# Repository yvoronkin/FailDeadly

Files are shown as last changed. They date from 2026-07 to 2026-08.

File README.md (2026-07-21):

# FailDeadly
### Fail Secure. Fail Deadly

FailDeadly is a USB hardware device designed to ensure the physical security of the server. It uses Hall sensors, along with magnets installed on the server lid, to detect any tampering attempt. To make it work, FailDeadly integrates with infrastructure and becomes the main or one of the sources of trust to pass server remote attestation.

FailDeadly stores secrets such as the sign key in SRAM as long as the MCU has power. In case of a tampering attempt when the server lid is moved, device power management detects a change in the magnetic field and cuts off the MCU power supply. FailDeadly destroy in memory secret in one second or less after the tamper event is detected. This time delay allows the MCU to notify the host system about the tamper event through message, SysRq, or hardware reset event.

To be able to keep secrets and reduce the number of maintenance events during power outages, FailDeadly has an Ionister to keep the SRAM powered.

### ** _Warning:_ FailDeadly achives it goals by valuing confidentiality more than availability. Be aware.**

Features:

* Physical tamper detection
* In-memory secret storage
* Power cut off on bare logic - no way to cancel 
* Secret destruction in case of tampering event
* SysRq or Reset pin could be used to reset the host system.
* On-board ionistor connector to keep secrets through power outages
* HashiCorp Vault integration
* On-device encrypt/decrypt, sign/verity operations.
* On-device key generation

Use cases:

* Hardening server physical security
* Remote server attestation
* Burn-out LUKS decryption keys



### TODO:
- [x] Hardware design v1.0 rev 001 
- [ ] Firmware 
- [ ] Software 
- [ ] HashiCorp Vault login plugin

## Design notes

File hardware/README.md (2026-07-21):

# FailDeadly hardware
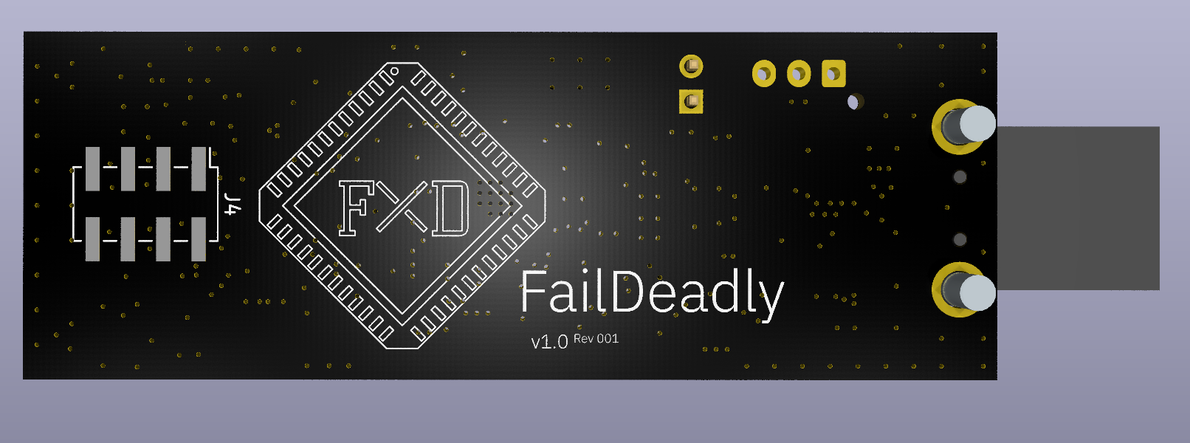
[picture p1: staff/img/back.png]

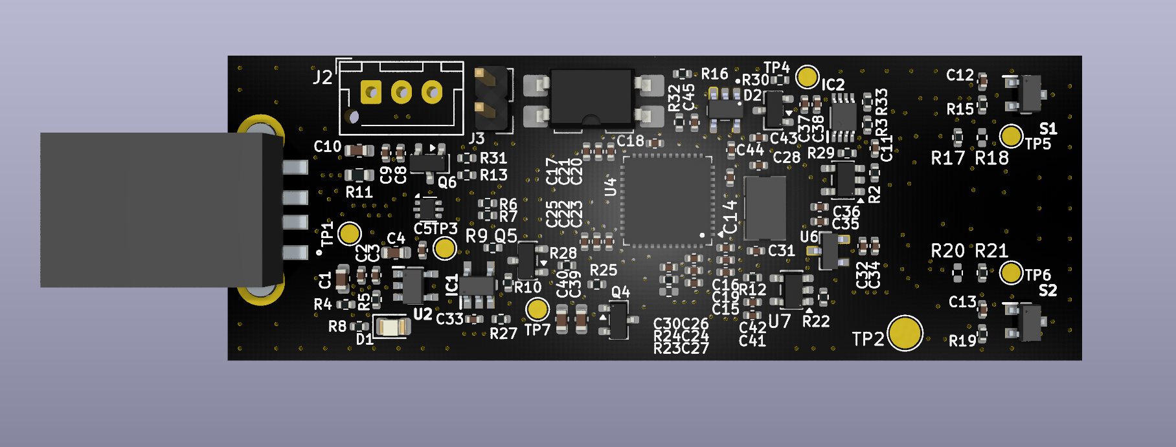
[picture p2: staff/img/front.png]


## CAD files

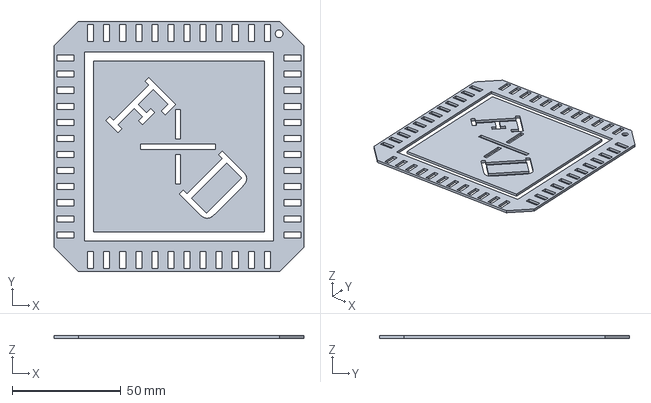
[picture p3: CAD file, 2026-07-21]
staff/logo/logo.FCStd
114.8 x 114.8 x 1.40 mm

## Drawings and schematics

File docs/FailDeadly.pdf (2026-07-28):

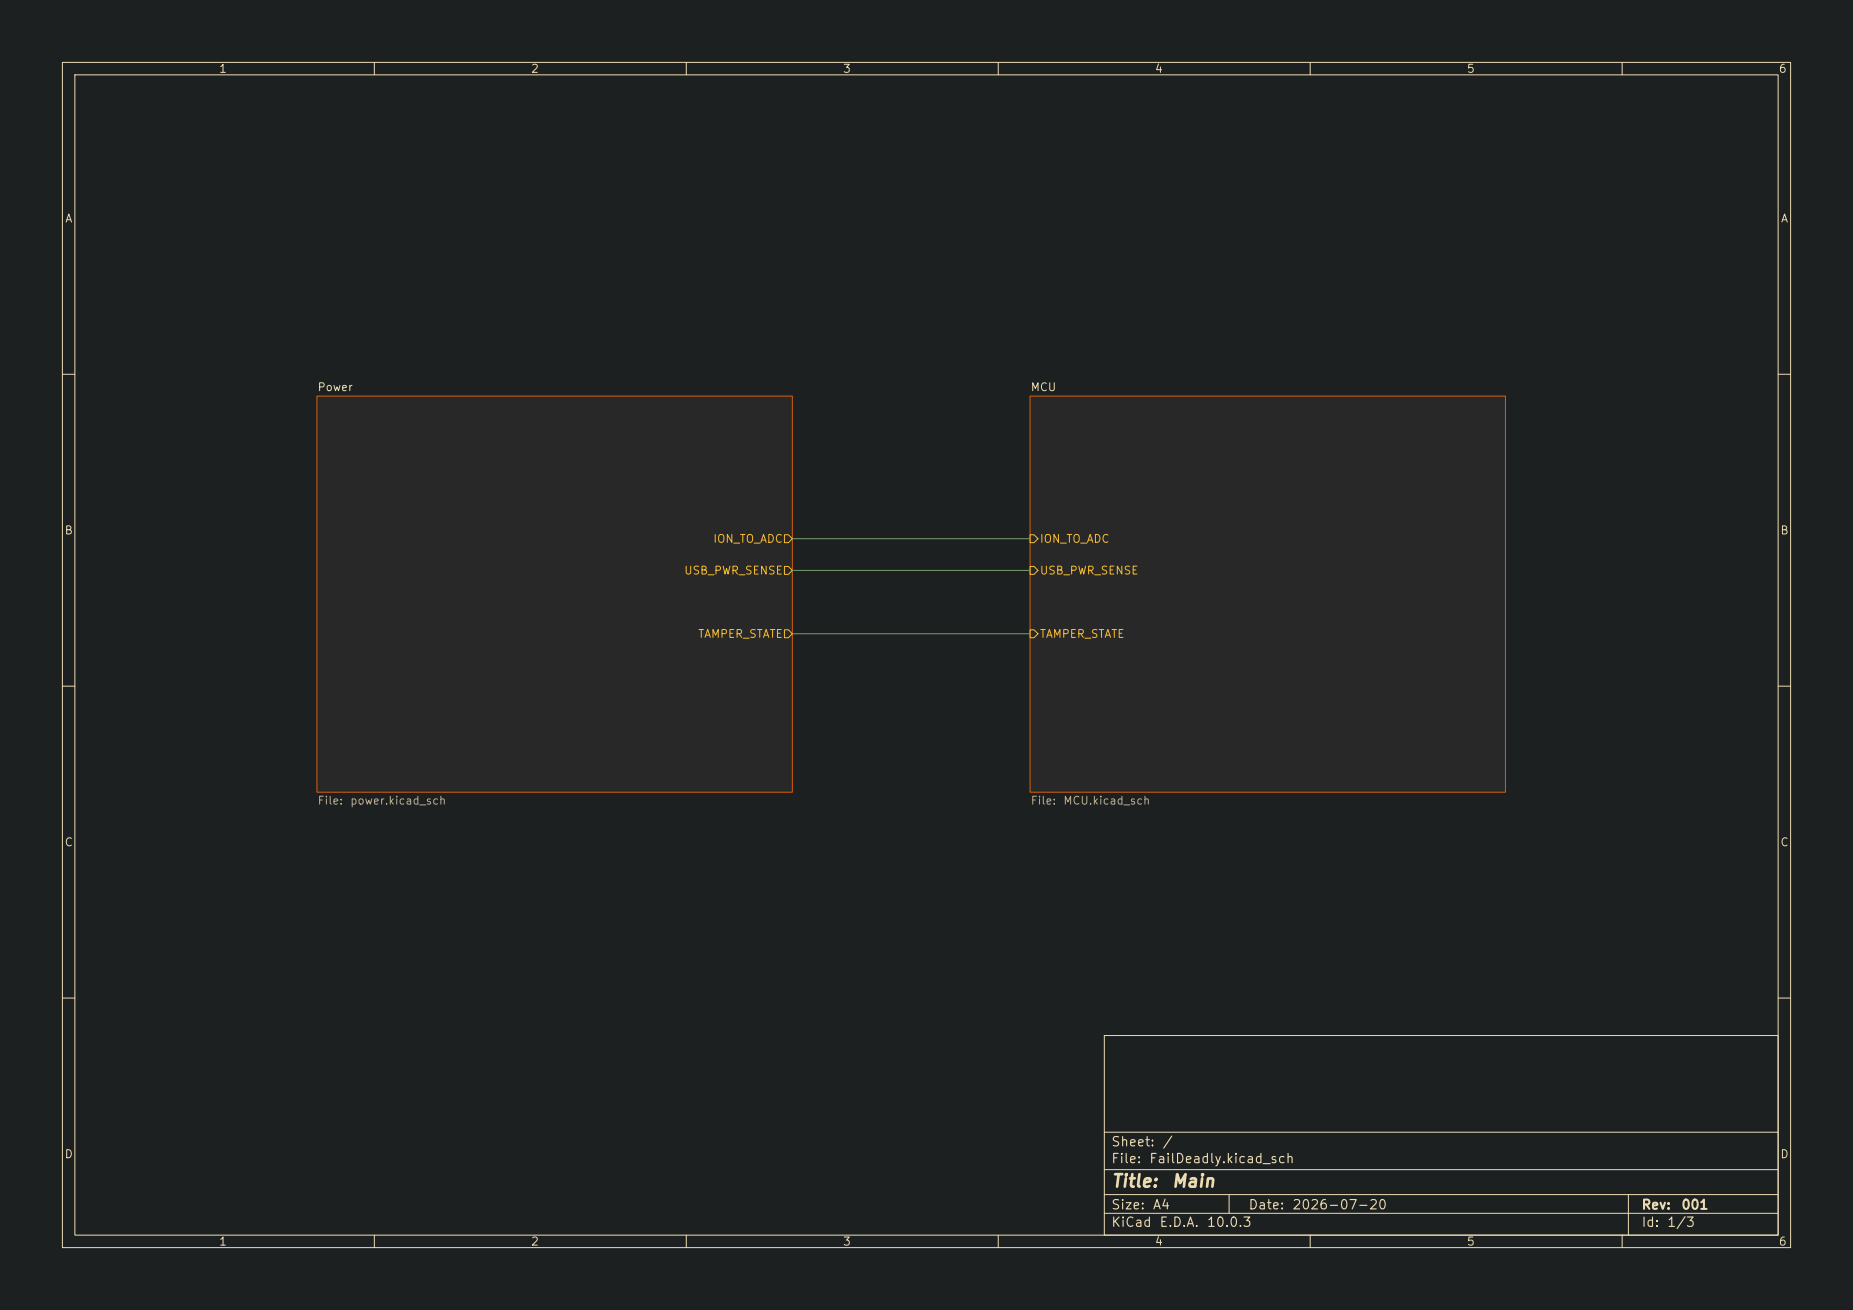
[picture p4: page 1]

Size: A4 | Rev: 001
KiCad E.D.A. 10.0.3 | Id: 1/3

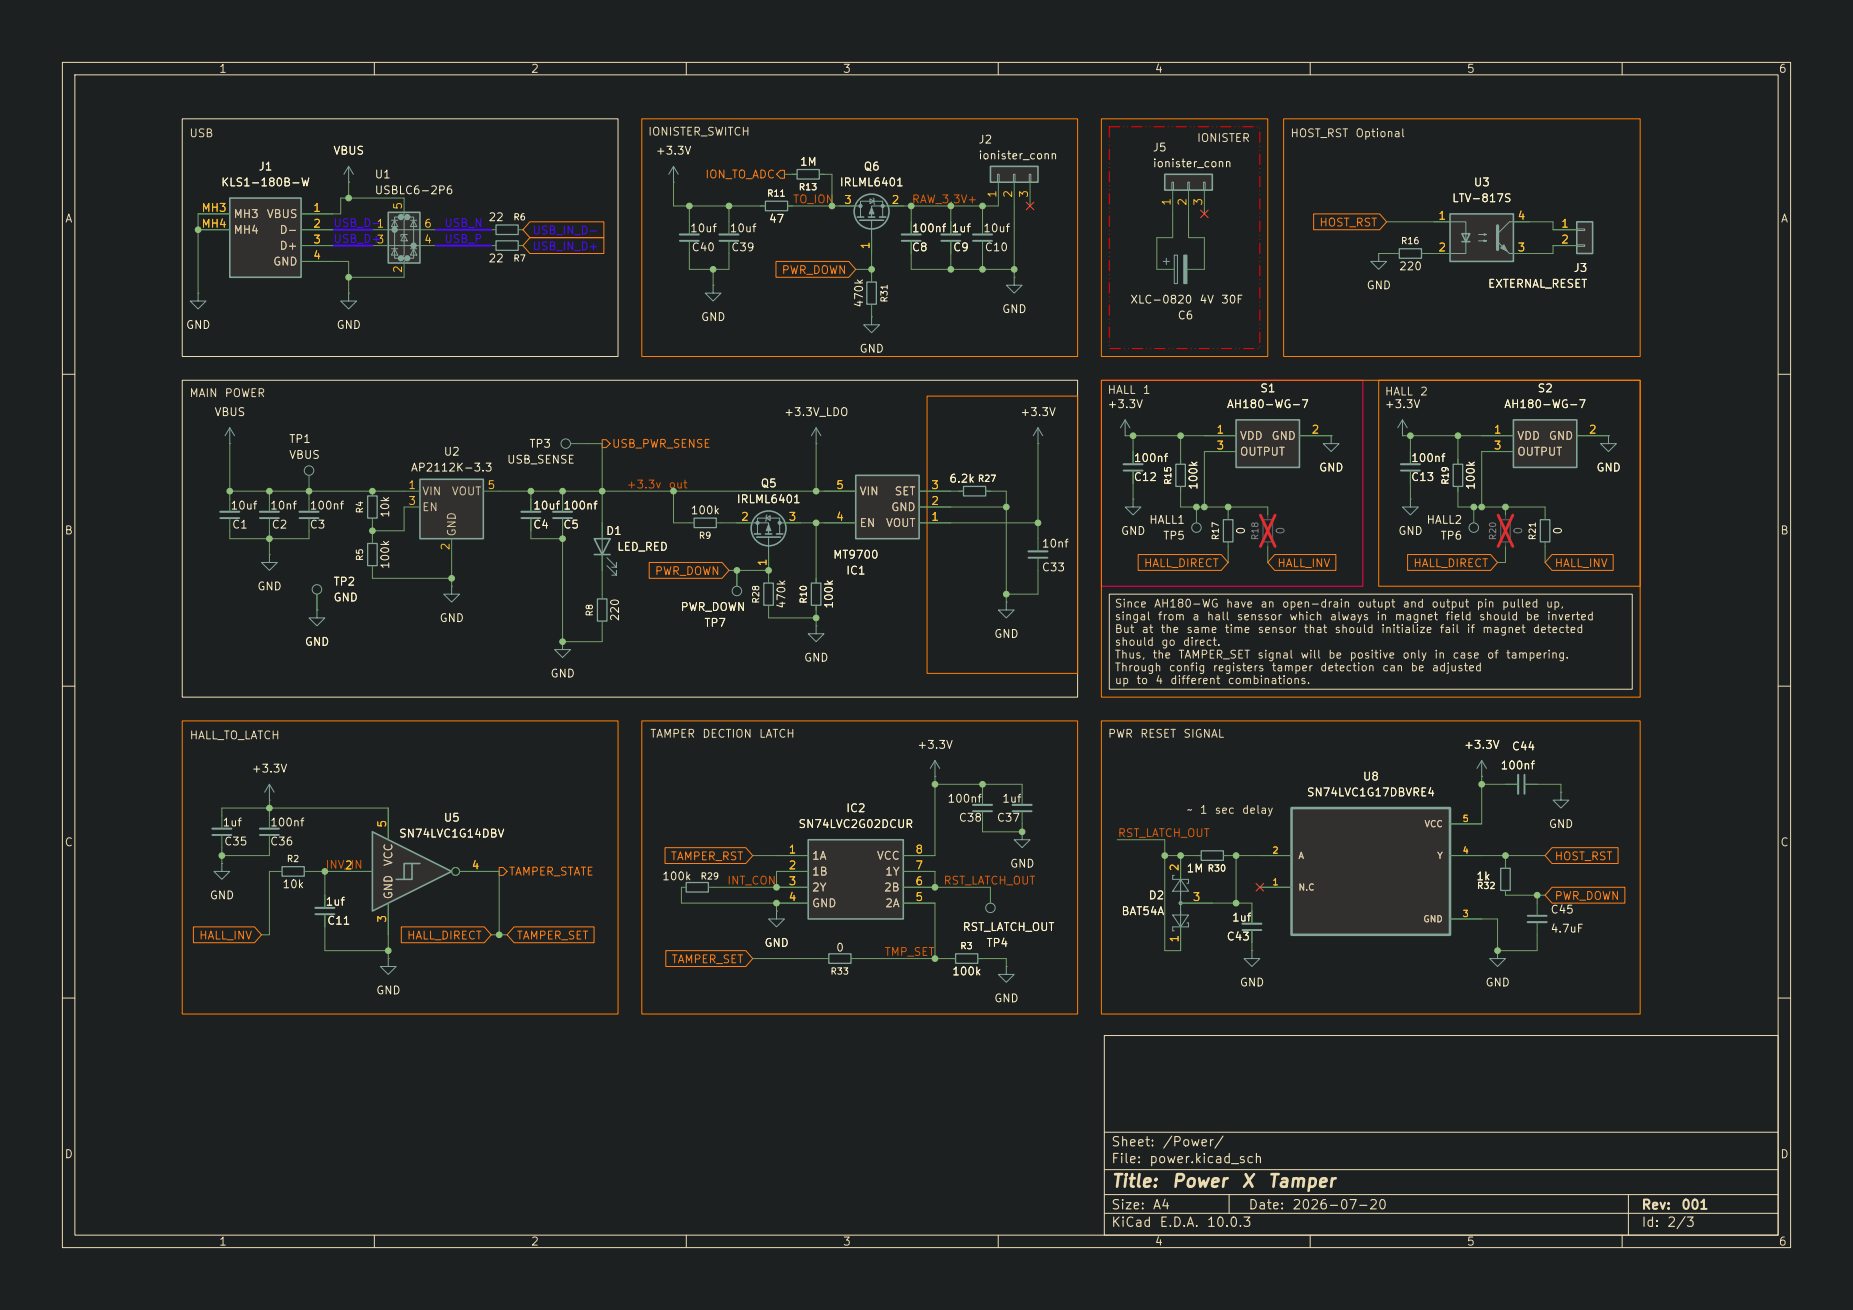
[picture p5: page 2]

Since AH180-WG have an open-drain outupt and output pin pulled up, singal from a hall senssor which always in magnet field should be inverted But at the same time sensor that should initialize fail if magnet detected should go direct. Thus, the TAMPER_SET signal will be positive only in case of tampering.

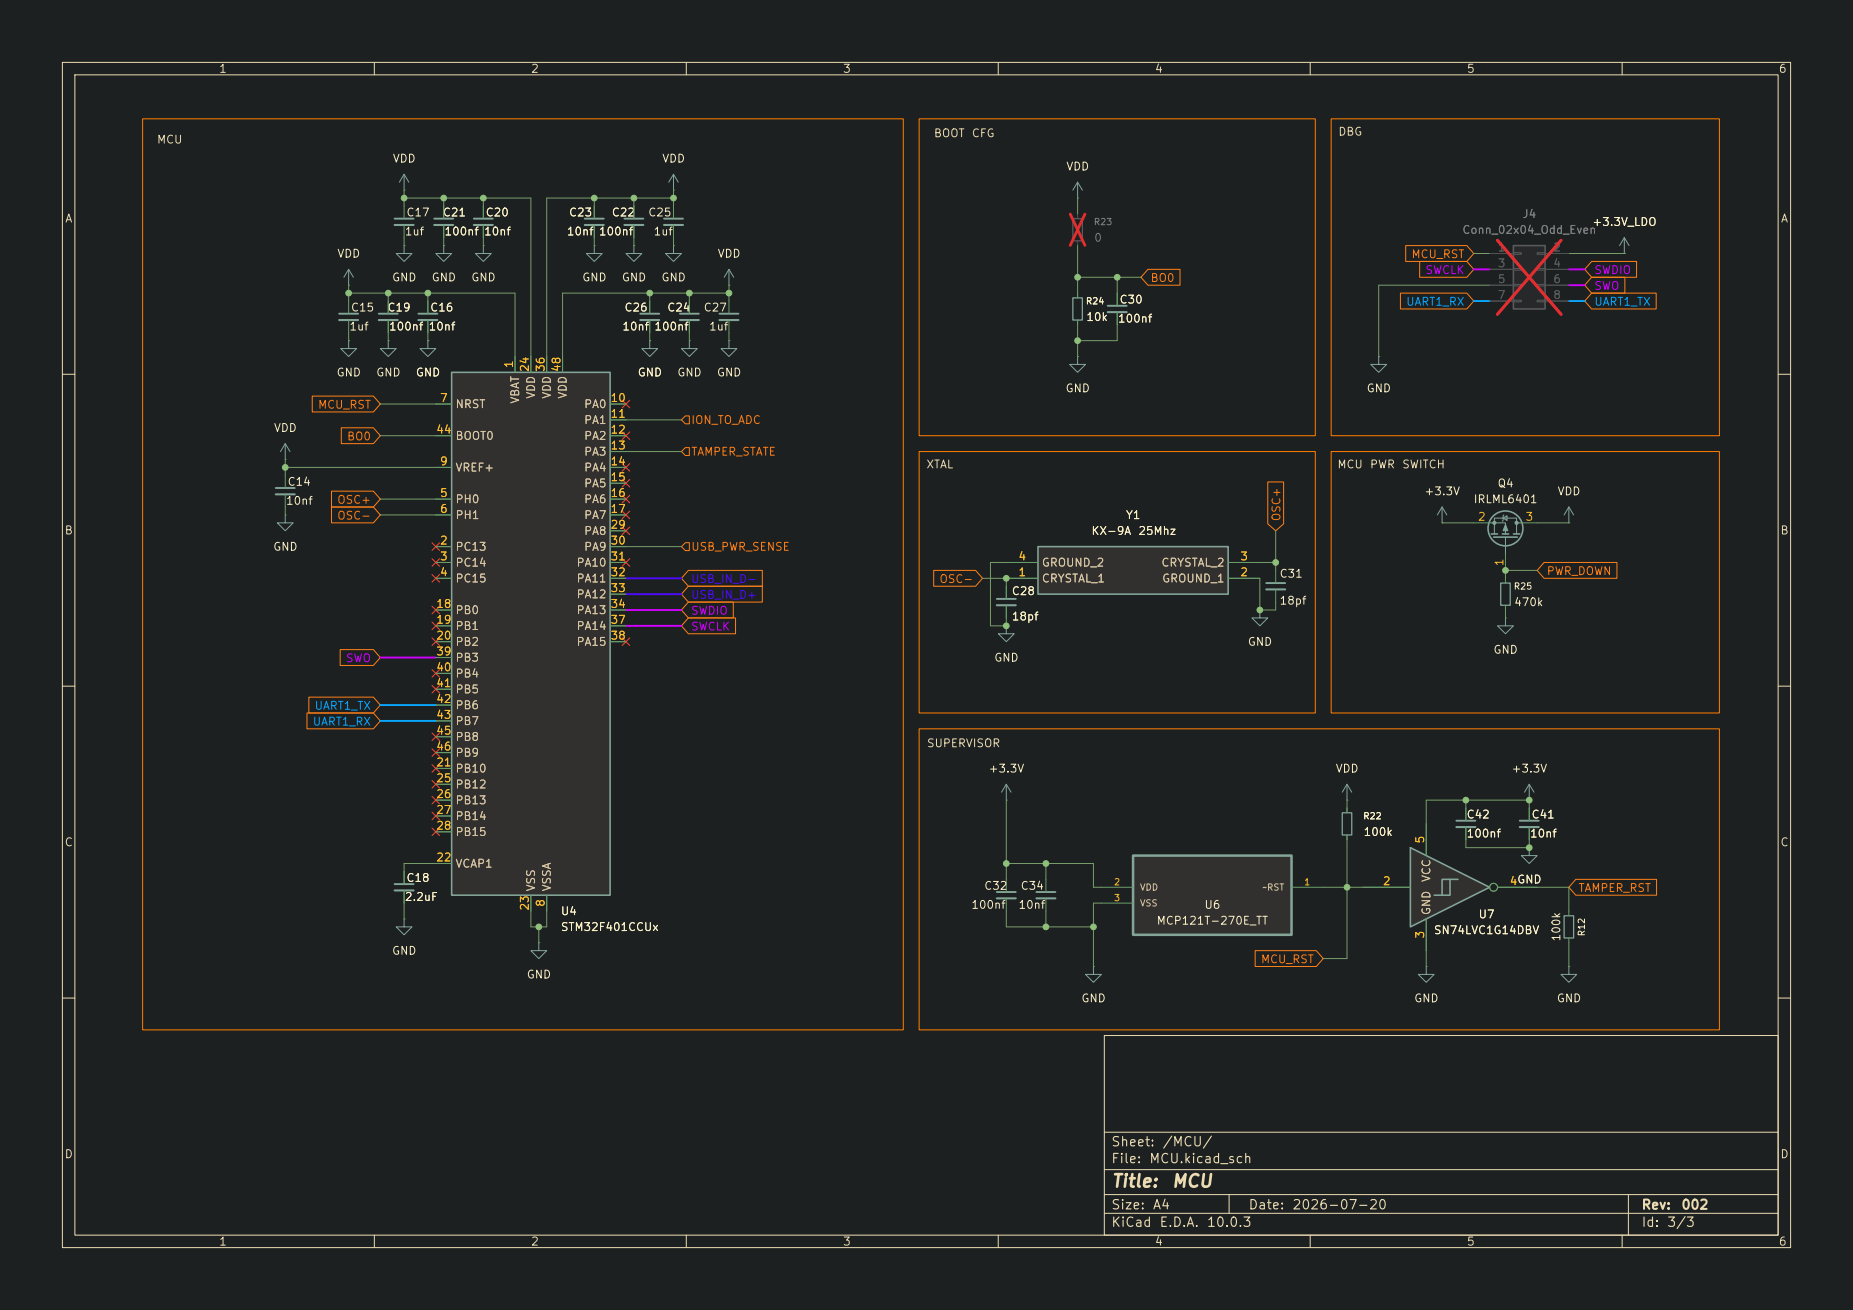
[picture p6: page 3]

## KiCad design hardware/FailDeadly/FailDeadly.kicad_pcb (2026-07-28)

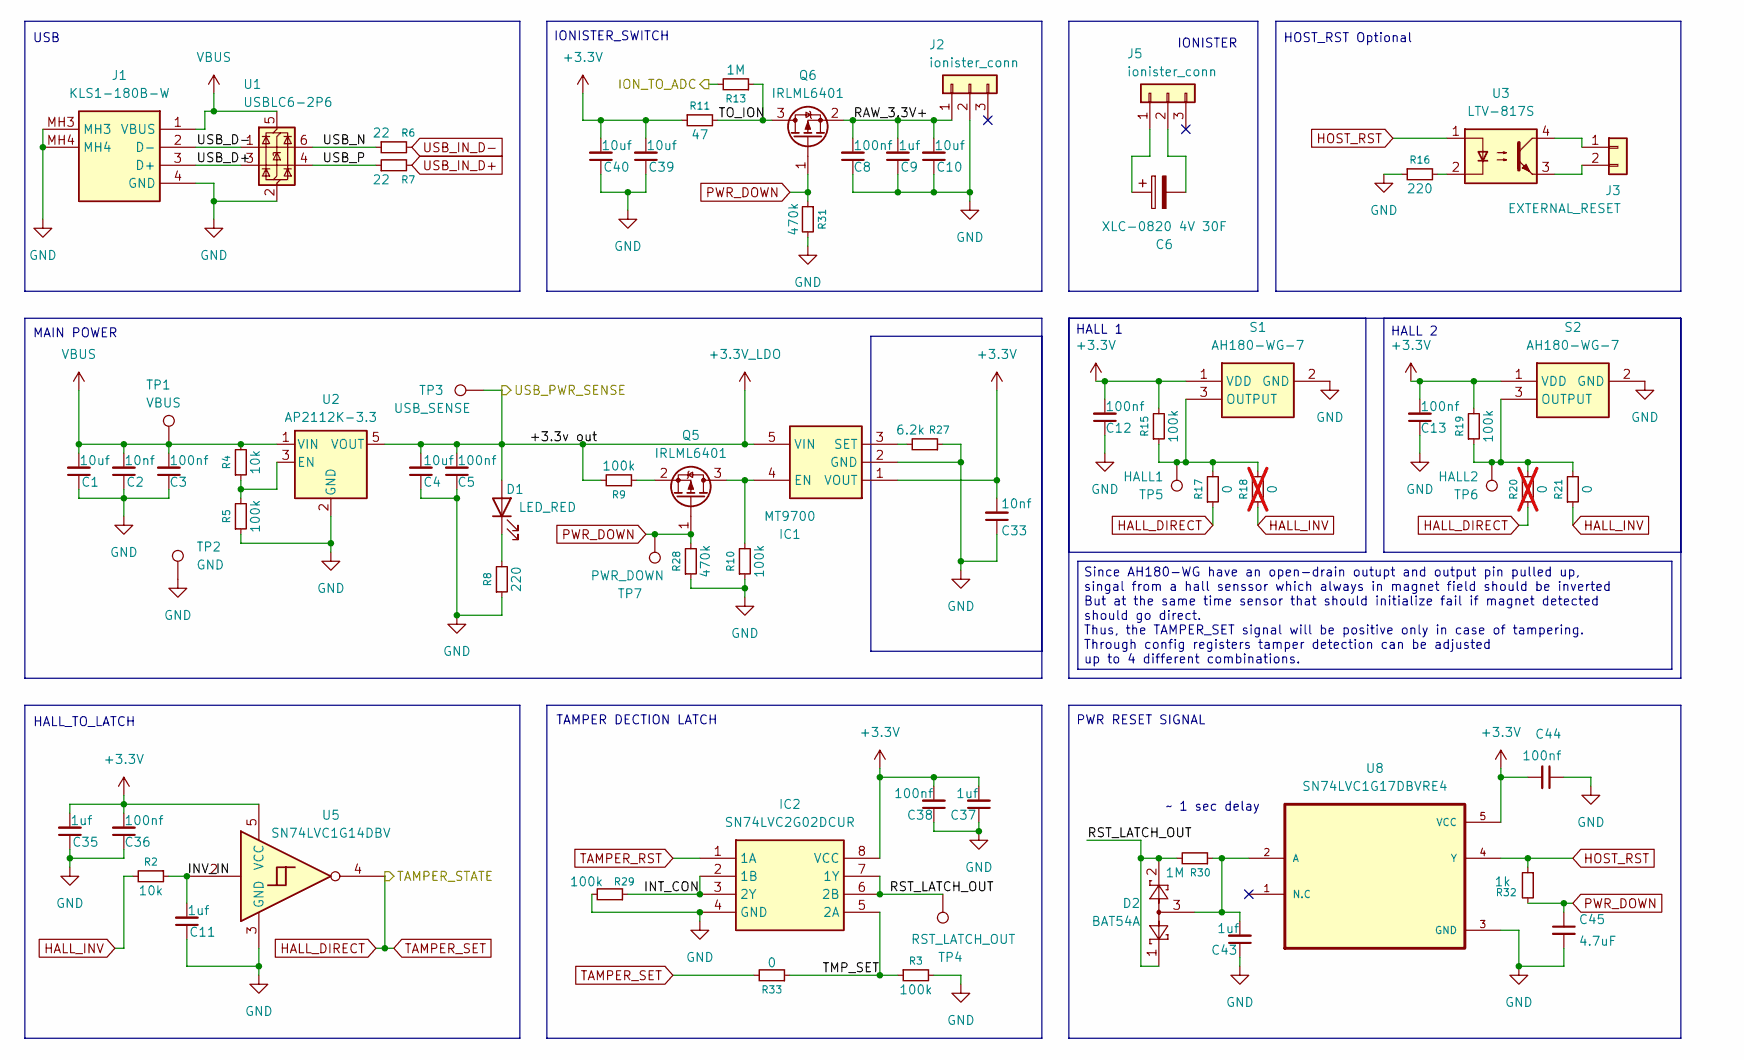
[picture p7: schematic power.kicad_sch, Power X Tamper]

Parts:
C1, C4, C10, C39, C40: 10uf; C_0603_1608Metric
C2, C33: 10nf; C_0402_1005Metric
C3, C5, C8, C12, C13, C36, C38, C44: 100nf; C_0402_1005Metric
C6: XLC-0820 4V 30F
C9, C11, C35, C37, C43: 1uf; C_0402_1005Metric
C45: 4.7uF; C_0603_1608Metric
D1: LED_RED; LED_0805_2012Metric
D2: BAT54A; SOT-23
IC1: MT9700; SOT95P280X135-5N; Manufacturer_Part_Number MT9700
IC2: SN74LVC2G02DCUR; SOP50P310X90-8N; Manufacturer_Part_Number SN74LVC2G02DCUR; Mouser Part Number 595-SN74LVC2G02DCUR
J1: KLS1-180B-W; KLS1180BW; Manufacturer_Part_Number KLS1-180B-W
J2, J5: ionister_conn; JST_XH_B3B-XH-AM_1x03_P2.50mm_Vertical
J3: EXTERNAL_RESET; PinHeader_1x02_P2.54mm_Vertical
Q5, Q6: IRLML6401; SOT-23
R2, R4: 10k; R_0402_1005Metric
R3, R5, R9, R10, R15, R19, R29: 100k; R_0402_1005Metric
R6, R7: 22; R_0402_1005Metric
R8, R16: 220; R_0402_1005Metric
R11: 47; R_0603_1608Metric
R13, R30: 1M; R_0402_1005Metric
R17, R21, R33: 0; R_0402_1005Metric
R18, R20: 0; R_0402_1005Metric; not fitted
R27: 6.2k; R_0402_1005Metric
R28, R31: 470k; R_0402_1005Metric
R32: 1k; R_0402_1005Metric
S1, S2: AH180-WG-7; AH180WG7; Manufacturer_Part_Number AH180-WG-7; Mouser Part Number 621-AH180-WG-7
TP1: VBUS; TestPoint_Pad_D1.5mm
TP2: GND; TestPoint_Pad_D2.5mm
TP3: USB_SENSE; TestPoint_Pad_D1.5mm
TP4: RST_LATCH_OUT; TestPoint_Pad_D1.5mm
TP5: HALL1; TestPoint_Pad_D1.5mm
TP6: HALL2; TestPoint_Pad_D1.5mm
TP7: PWR_DOWN; TestPoint_Pad_D1.5mm
U1: USBLC6-2P6; SOT-666
U2: AP2112K-3.3; SOT-23-5
U3: LTV-817S; SMDIP-4_W9.53mm
U5: SN74LVC1G14DBV; SOT-23-5
U8: SN74LVC1G17DBVRE4; SOT95P280X145-5N

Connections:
+3.3V: C12.2, C13.2, C33.2, C35.2, C36.2, C37.2, C38.2, C39.2, C40.2, C44.2, IC1.1 (VOUT), IC2.8 (VCC), R11.1, R15.2, R19.2, S1.1 (VDD), S2.1 (VDD), U5.5 (VCC), U8.5 (VCC); also elsewhere on the board
+3.3V_LDO: C4.2, C5.2, D1.2 (A), IC1.5 (VIN), R9.2, TP3.1 (1_1), U2.5 (VOUT); also elsewhere on the board
/MCU/ION_TO_ADC: R13.2; also elsewhere on the board
/Power/INT_CON: IC2.2 (1B), IC2.3 (2Y), R29.1
/Power/INV_IN: C11.2, R2.1, U5.2
/Power/RAW_3.3V+: C8.2, C9.2, C10.2, J2.1, Q6.2 (S)
/Power/RST_LATCH_OUT: D2.1, D2.2, IC2.6 (2B), IC2.7 (1Y), R30.2, TP4.1 (1_1)
/Power/TMP_SET: IC2.5 (2A), R3.1, R33.1
/Power/TO_ION: Q6.3 (D), R11.2, R13.1
/Power/USB_D+: J1.3 (D+), U1.3 (I/O2)
/Power/USB_D-: J1.2 (D-), U1.1 (I/O1)
/Power/USB_N: R6.1, U1.6 (I/O1)
/Power/USB_P: R7.1, U1.4 (I/O2)
GND: C1.1, C2.1, C3.1, C4.1, C5.1, C8.1, C9.1, C10.1, C11.1, C12.1, C13.1, C33.1, C35.1, C36.1, C37.1, C38.1, C39.1, C40.1, C43.1, C44.1, C45.2, IC1.2 (GND), IC2.4 (GND), J1.4 (GND), J1.MH3, J1.MH4, J2.2, R3.2, R5.1, R8.1, R10.1, R16.1, R27.1, R28.1, R29.2, R31.2, S1.2 (GND), S2.2 (GND), TP2.1 (1_1), U1.2 (GND), U2.2 (GND), U5.3 (GND), U8.3 (GND); also elsewhere on the board
HALL_DIRECT: R17.1, R20.1, R33.2, U5.4; also elsewhere on the board
HALL_INV: R2.2, R18.1, R21.1
HOST_RST: R32.1, U3.1, U8.4 (Y)
unnamed: C6.1, J5.1
unnamed: C6.2, J5.2
unnamed: D1.1 (K), R8.2
unnamed: IC1.4 (EN), Q5.3 (D), R10.2
unnamed: IC1.3 (SET), R27.2
unnamed: J3.1, U3.4
unnamed: J3.2, U3.3
unnamed: Q5.2 (S), R9.1
unnamed: R16.2, U3.2
unnamed: R15.1, R17.2, R18.2, S1.3 (OUTPUT), TP5.1 (1_1)
unnamed: R19.1, R20.2, R21.2, S2.3 (OUTPUT), TP6.1 (1_1)
unnamed: R4.1, R5.2, U2.3 (EN)
unnamed: C43.2, D2.3, R30.1, U8.2 (A)
PWR_DOWN: C45.1, Q5.1 (G), Q6.1 (G), R28.2, R31.1, R32.2, TP7.1 (1_1); also elsewhere on the board
TAMPER_RST: IC2.1 (1A); also elsewhere on the board
USB_IN_D+: R7.2; also elsewhere on the board
USB_IN_D-: R6.2; also elsewhere on the board
VBUS: C1.2, C2.2, C3.2, J1.1 (VBUS), R4.2, TP1.1 (1_1), U1.5 (VBUS), U2.1 (VIN)

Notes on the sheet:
HALL_TO_LATCH
USB
~ 1 sec delay
IONISTER
HALL 2
TAMPER DECTION LATCH
MAIN POWER
HOST_RST Optional
HALL 1
PWR RESET SIGNAL
Since AH180-WG have an open-drain outupt and output pin pulled up, singal from a hall senssor which always in magnet field should be inverted But at the same time sensor that should initialize fail if magnet detected should go direct. Thus, the TAMPER_SET signal will be positive only in case of tam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
IONISTER_SWITCH

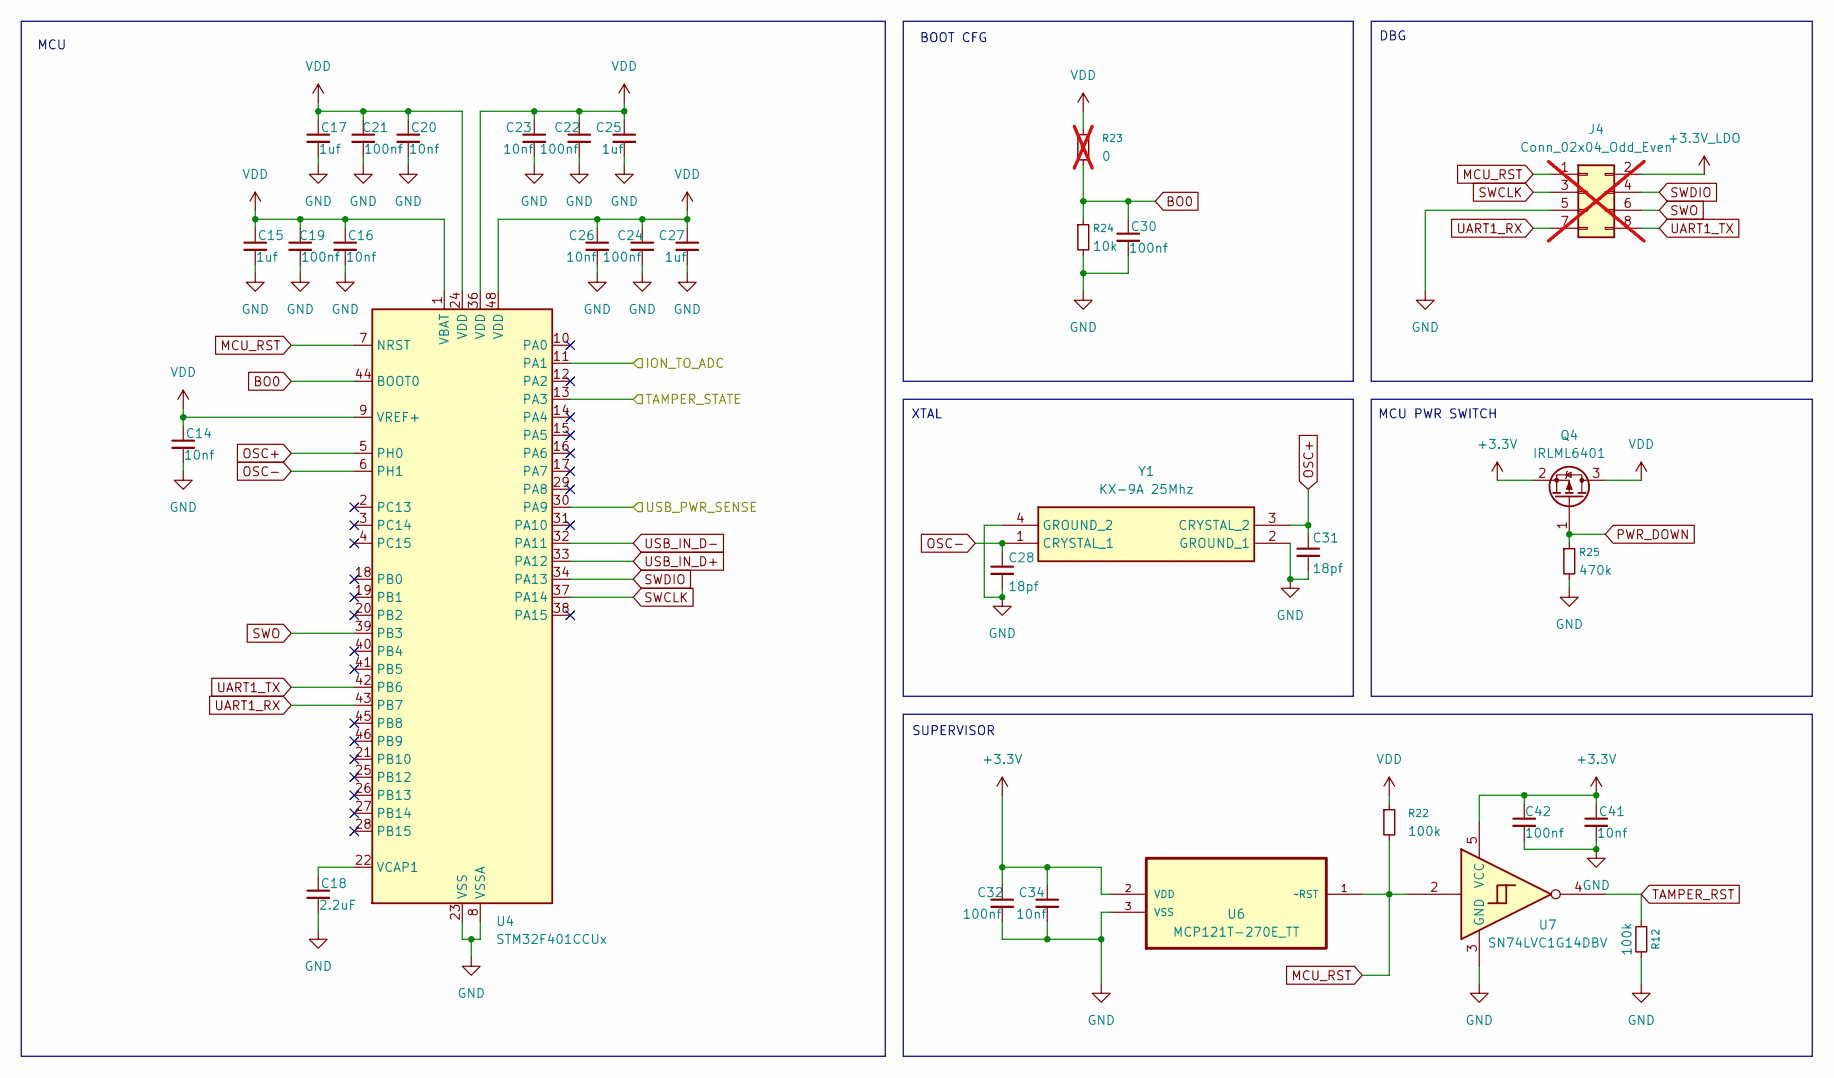
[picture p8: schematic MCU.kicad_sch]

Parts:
C14, C16, C20, C23, C26, C34, C41: 10nf; C_0402_1005Metric
C15, C17, C25, C27: 1uf; C_0402_1005Metric
C18: 2.2uF; C_0603_1608Metric
C19, C21, C22, C24, C30, C32, C42: 100nf; C_0402_1005Metric
C28, C31: 18pf; C_0402_1005Metric
J4: Conn_02x04_Odd_Even; PinHeader_2x04_P2.54mm_Vertical_SMD; not fitted
Q4: IRLML6401; SOT-23
R12, R22: 100k; R_0402_1005Metric
R23: 0; R_0402_1005Metric; not fitted
R24: 10k; R_0402_1005Metric
R25: 470k; R_0402_1005Metric
U4: STM32F401CCUx; QFN-48-1EP_7x7mm_P0.5mm_EP5.6x5.6mm
U6: MCP121T-270E_TT; SOT95P237X112-3N; MPN MCP121T-270E/TT
U7: SN74LVC1G14DBV; SOT-23-5
Y1: KX-9A 25Mhz; KX9A; Manufacturer_Part_Number KX-9A

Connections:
+3.3V: C32.1, C34.1, C41.1, C42.1, Q4.2 (S), U6.2 (VDD), U7.5 (VCC); also elsewhere on the board
+3.3V_LDO: J4.2, U4.30 (PA9); also elsewhere on the board
/MCU/ION_TO_ADC: U4.11 (PA1); also elsewhere on the board
BO0: C30.1, R23.2, R24.1, U4.44 (BOOT0)
GND: C14.2, C15.2, C16.2, C17.2, C18.2, C19.2, C20.2, C21.2, C22.2, C23.2, C24.2, C25.2, C26.2, C27.2, C28.2, C30.2, C31.2, C32.2, C34.2, C41.2, C42.2, J4.5, R12.2, R24.2, R25.2, U4.8 (VSSA), U4.23 (VSS), U4.35 (VSS), U4.47 (VSS), U4.49 (VSS), U6.3 (VSS), U7.3 (GND), Y1.2 (GROUND_1), Y1.4 (GROUND_2); also elsewhere on the board
HALL_DIRECT: U4.13 (PA3); also elsewhere on the board
MCU_RST: J4.1, R22.2, U4.7 (NRST), U6.1 (~RST), U7.2
unnamed: C18.1, U4.22 (VCAP1)
OSC+: C31.1, U4.5 (PH0), Y1.3 (CRYSTAL_2)
OSC-: C28.1, U4.6 (PH1), Y1.1 (CRYSTAL_1)
PWR_DOWN: Q4.1 (G), R25.1; also elsewhere on the board
SWCLK: J4.3, U4.37 (PA14)
SWDIO: J4.4, U4.34 (PA13)
SWO: J4.6, U4.39 (PB3)
TAMPER_RST: R12.1, U7.4; also elsewhere on the board
UART1_RX: J4.7, U4.43 (PB7)
UART1_TX: J4.8, U4.42 (PB6)
USB_IN_D+: U4.33 (PA12); also elsewhere on the board
USB_IN_D-: U4.32 (PA11); also elsewhere on the board
VDD: C14.1, C15.1, C16.1, C17.1, C19.1, C20.1, C21.1, C22.1, C23.1, C24.1, C25.1, C26.1, C27.1, Q4.3 (D), R22.1, R23.1, U4.1 (VBAT), U4.9 (VREF+), U4.24 (VDD), U4.36 (VDD), U4.48 (VDD)

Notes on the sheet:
SUPERVISOR
MCU PWR SWITCH
DBG
BOOT CFG
XTAL
MCU

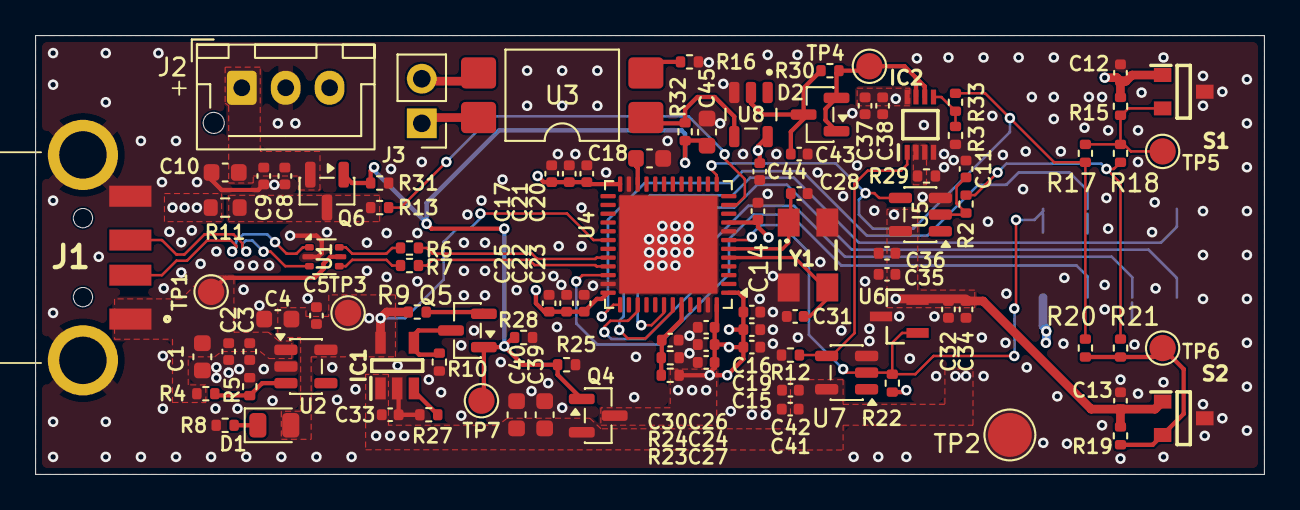
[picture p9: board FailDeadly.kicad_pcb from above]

Board: 4 copper layers, 70.0 x 25.0 mm, 101 parts (1 on the bottom side), 44 nets.

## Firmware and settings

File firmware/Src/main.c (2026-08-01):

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
/* Includes ------------------------------------------------------------------*/
#include "main.h"
#include "adc.h"
#include "crc.h"
#include "dma.h"
#include "tim.h"
#include "usart.h"
#include "usb_device.h"
#include "gpio.h"

/* USER CODE BEGIN Includes */

#include "FreeRTOS.h"
#include "task.h"

#include "fd_tasks.h"
#include "fd_crypto.h"
#include "fd_log.h"
#include "stm32_assert.h"
#include "uptime.h"

/* USER CODE END Includes */


/* USER CODE BEGIN PV */

static const 
unsigned char banner[] = 
    "  ███████████            ███  ████  ██████████                          █████ ████            \r\n" 
    " ▒▒███▒▒▒▒▒▒█           ▒▒▒  ▒▒███ ▒▒███▒▒▒▒███                        ▒▒███ ▒▒███            \r\n" 
    "  ▒███   █ ▒   ██████   ████  ▒███  ▒███   ▒▒███  ██████   ██████    ███████  ▒███  █████ ████\r\n"
    "  ▒███████    ▒▒▒▒▒███ ▒▒███  ▒███  ▒███    ▒███ ███▒▒███ ▒▒▒▒▒███  ███▒▒███  ▒███ ▒▒███ ▒███ \r\n" 
    "  ▒███▒▒▒█     ███████  ▒███  ▒███  ▒███    ▒███▒███████   ███████ ▒███ ▒███  ▒███  ▒███ ▒███ \r\n" 
    "  ▒███  ▒     ███▒▒███  ▒███  ▒███  ▒███    ███ ▒███▒▒▒   ███▒▒███ ▒███ ▒███  ▒███  ▒███ ▒███ \r\n" 
    "  █████      ▒▒████████ █████ █████ ██████████  ▒▒██████ ▒▒████████▒▒████████ █████ ▒▒███████ \r\n" 
    " ▒▒▒▒▒        ▒▒▒▒▒▒▒▒ ▒▒▒▒▒ ▒▒▒▒▒ ▒▒▒▒▒▒▒▒▒▒    ▒▒▒▒▒▒   ▒▒▒▒▒▒▒▒  ▒▒▒▒▒▒▒▒ ▒▒▒▒▒   ▒▒▒▒▒███ \r\n" 
    "                                                                                     ███ ▒███ \r\n" 
    "                                                                                    ▒▒██████  \r\n" 
    "                                                                                     ▒▒▒▒▒▒   \r\n" 
    "\0";

static const 
unsigned char gone4good_msg[] = "\r\nAt this point, crypto keys are gone for good.\r\n\0";

/* USER CODE END PV */

void SystemClock_Config(void);
/* USER CODE BEGIN 0 */

extern uint32_t __privileged_data_load_start__;
extern uint32_t __privileged_data_start__;
extern uint32_t __privileged_data_actual_end__;

static void InitPrivilegedData(void)
{
    const uint32_t *src = &__privileged_data_load_start__;
    uint32_t *dst = &__privileged_data_start__;
    const uint32_t *end = &__privileged_data_actual_end__;

    while (dst < end)
    {
        *dst++ = *src++;
    }
}

/* USER CODE END 0 */

/**
  * @brief  The application entry point.
  * @retval int
  */
int main(void)
{

  /* USER CODE BEGIN 1 */
    InitPrivilegedData();
  /* USER CODE END 1 */

  /* MCU Configuration--------------------------------------------------------*/

  /* Reset of all peripherals, Initializes the Flash interface and the Systick. */
  HAL_Init();

  /* Configure the system clock */
  SystemClock_Config();

  /* USER CODE BEGIN SysInit */

    // clocks initialized, now reset fd crypto storage
    FDCryptoClear();


  /* USER CODE END SysInit */

  /* Initialize all configured peripherals */
  MX_GPIO_Init();
  MX_DMA_Init();
  MX_ADC1_Init();
  MX_CRC_Init();
  MX_USART1_UART_Init();
  MX_USB_DEVICE_Init();
  MX_TIM2_Init();
  MX_TIM4_Init();
  /* USER CODE BEGIN 2 */

    assert_storage_reset();
    uptime_data_reset();
    FDSendLog(banner, strlen((const char *)banner), 0, 0);
    FDSendLog(gone4good_msg, strlen((const char *)gone4good_msg), 0, 0);

    FDTasksInit();
    vTaskStartScheduler();

    // should never reach this part, something bad happend with scheduler
    assert_param(0 == 1);

  /* USER CODE END 2 */

  /* Infinite loop */
  /* USER CODE BEGIN WHILE */
    NVIC_SystemReset();
    while (1)
    {
    /* USER CODE END WHILE */

    /* USER CODE BEGIN 3 */
    }
  /* USER CODE END 3 */
}

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
/* USER CODE BEGIN 4 */

void vApplicationGetIdleTaskMemory( StaticTask_t **ppxIdleTaskTCBBuffer,
                                      StackType_t **ppxIdleTaskStackBuffer,
                                      uint32_t *pulIdleTaskStackSize )
{
    static StaticTask_t xIdleTaskTCB;
    static StackType_t uxIdleTaskStack[ configMINIMAL_STACK_SIZE ];

    *ppxIdleTaskTCBBuffer = &xIdleTaskTCB;
    *ppxIdleTaskStackBuffer = uxIdleTaskStack;
    *pulIdleTaskStackSize = configMINIMAL_STACK_SIZE;
}

void vApplicationGetTimerTaskMemory( StaticTask_t **ppxTimerTaskTCBBuffer,
                                      StackType_t **ppxTimerTaskStackBuffer,
                                      uint32_t *pulTimerTaskStackSize )
{
    static StaticTask_t xTimerTaskTCB;
    static StackType_t uxTimerTaskStack[ configTIMER_TASK_STACK_DEPTH ];

    *ppxTimerTaskTCBBuffer = &xTimerTaskTCB;
    *ppxTimerTaskStackBuffer = uxTimerTaskStack;
    *pulTimerTaskStackSize = configTIMER_TASK_STACK_DEPTH;
}

/* USER CODE END 4 */

/**
  * @brief  Period elapsed callback in non blocking mode
  * @note   This function is called  when TIM3 interrupt took place, inside
  * HAL_TIM_IRQHandler(). It makes a direct call to HAL_IncTick() to increment
  * a global variable "uwTick" used as application time base.
  * @param  htim : TIM handle
  * @retval None
  */
void HAL_TIM_PeriodElapsedCallback(TIM_HandleTypeDef *htim)
{
  if (htim->Instance == TIM3)
  {
    HAL_IncTick();
  }
  /* USER CODE BEGIN Callback 1 */
    if (htim->Instance == TIM4)
    {
        uptime_update_isr();
    }
  /* USER CODE END Callback 1 */
}

/**
  * @brief  This function is executed in case of error occurrence.
  * @retval None
  */
void Error_Handler(void)
{
  /* USER CODE BEGIN Error_Handler_Debug */
  /* User can add his own implementation to report the HAL error return state */
  __disable_irq();
  while (1)
  {
  }
  /* USER CODE END Error_Handler_Debug */
}
#ifdef USE_FULL_ASSERT
/**
  * @brief  Reports the name of the source file and the source line number
  *         where the assert_param error has occurred.
  * @param  file: pointer to the source file name
  * @param  line: assert_param error line source number
  * @retval None
  */
void assert_failed(uint8_t *file, uint32_t line)
{
  /* USER CODE BEGIN 6 */

    /* Can't get rid of it if I want to regen some code through stm32pio. */
    app_assert_failed(file, line);

  /* USER CODE END 6 */
}
#endif /* USE_FULL_ASSERT */

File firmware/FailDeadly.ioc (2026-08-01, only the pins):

Mcu.UserName=STM32F401CCUx
PA1.GPIO_Label=ion_to_adc
PA1.Signal=ADCx_IN1
PA11.Signal=USB_OTG_FS_DM
PA12.Signal=USB_OTG_FS_DP
PA13.Signal=SYS_JTMS-SWDIO
PA14.Signal=SYS_JTCK-SWCLK
PA3.GPIO_Label=tamper_state
PA3.Signal=GPXTI3
PA9.GPIO_Label=usb_power_sense
PA9.Signal=GPXTI9
PB6.Signal=USART1_TX
PB7.Signal=USART1_RX
PC13-ANTI_TAMP.GPIO_Label=debug_led
PC13-ANTI_TAMP.Signal=GPIO_Output

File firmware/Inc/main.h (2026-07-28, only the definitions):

#define debug_led_Pin GPIO_PIN_13
#define debug_led_GPIO_Port GPIOC
#define ion_to_adc_Pin GPIO_PIN_1
#define ion_to_adc_GPIO_Port GPIOA
#define tamper_state_Pin GPIO_PIN_3
#define tamper_state_GPIO_Port GPIOA
#define tamper_state_EXTI_IRQn EXTI3_IRQn
#define usb_power_sense_Pin GPIO_PIN_9
#define usb_power_sense_GPIO_Port GPIOA
#define usb_power_sense_EXTI_IRQn EXTI9_5_IRQn

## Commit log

2026-07-21 Hardware v1.0 rev 001
    [FailDeadly-B_Cu.gbr, FailDeadly-B_Mask.gbr, FailDeadly-B_Paste.gbr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]
2026-07-23 Schematic v1.0 rev 001
2026-07-28 Small changes in schematic
    The crystal oscillator was changed from 24 MHz to 25 MHz so that the original board and the STM32 Green Pill (test board) were compatible in the oscillator configuration in the firmware.
    [FailDeadly.kicad_pcb, MCU.kicad_sch]
2026-07-31 Logs and some fixes
    - USART1 DMA enabled
    - ADC1 DMA enabled
    - Logo added
    - Log over USART added
    - Assert_param instead of 'if'
    - Macros.h updated
    - Fixed problems in vcp_comm
    [FailDeadly.ioc, assert.c, fd_log.c]
2026-07-31 Assert functions updated
    Can't get rid of assert_failed in main.c, since CubeMX re-generates it; made a redirect.
    + Assert storage flush/reset
    [assert.c, main.c]
2026-08-01 U64 uptime counter
    -TIM4 as an interrupt source for uptime counter

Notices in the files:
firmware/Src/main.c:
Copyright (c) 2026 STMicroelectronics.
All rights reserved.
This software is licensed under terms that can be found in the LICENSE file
